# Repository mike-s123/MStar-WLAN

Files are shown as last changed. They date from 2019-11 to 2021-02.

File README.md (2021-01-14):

# MStar-WLAN

### What's new

Now supports collecting data in an [RRD](https://oss.oetiker.ch/rrdtool/), and charting that data using [JavascriptRRD](http://javascriptrrd.sourceforge.net). The interval for traditional logging can now be set. Updated hardware for USB Type-C.

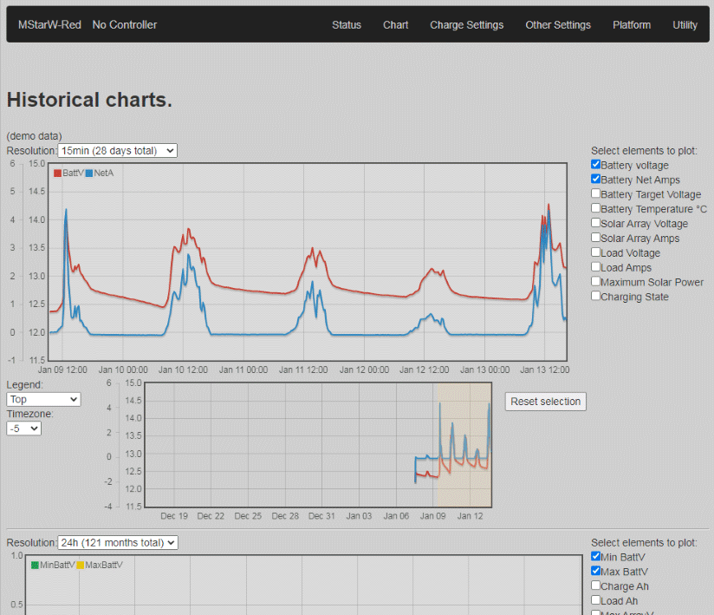
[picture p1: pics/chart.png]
image of chart


## Overview

This project includes both a software and hardware design for interfacing to a [Morningstar](https://www.morningstarcorp.com/) solar controller via wireless LAN (WiFi). It's 99.99% working, with features still being added. The development core is an ESP32-WROVER-B 16MB (~$5 from Mouser) or an ESP32 DevkitC v4. A complete build should be ~$40, ignoring your time. Those platforms were chosen because they're available with a relatively large flash (16 MiB) for storing files, which allows having documentation and support for multiple solar controllers on-board. Supports MS-View compatible logging of controller info to an SD card, in addition to a debugging log. There's support for monitoring and configuration via a web interface, Modbus/TCP, and a RESTful JSON API. The UI fits well on a cell phone screen.

A core with less flash memory should work fine as long as the "data" directory will fit. The code supports moving content from flash to the SD Card. If a file is not found in flash, it will look for it on the SD Card. Delete everything in the "data" directory, copy everything from "data-small" into "data", and then copy everything in the "Put on SD Card - small" directory onto an SD Card to use an ESP32 board with less flash. The additional flash memory on the recommended modules is there in order to support all the static files even without an SD Card present. An SD Card is required for logging and charting.

It is written using the [Arduino IDE](https://www.arduino.cc/en/Main/Software), which is a bit "odd", hence code being split for clarity amongst multiple .h files. If you know how to do it better, please contribute. Yes, I know some of the code is butt-ugly. But it works. Function over form.

The printed circuit board was done in [Eagle](https://www.autodesk.com/products/eagle/overview).

Development has been done testing against the Prostar MPPT and Prostar PWM Gen3 controllers, and the information/config files for those have been provided. Other controllers will need to have register definition .csv files (see data/csv_file_desc.txt) added. Might need to do some work for register datatypes - Morningstar has many (really, what were they thinking creating one based on a 16 bit int, n·316.67·2^-15, and multiple similar) and they've changed over time. It should also be able to support Sunsavers (SSDuo, SS-MPPT), and Tristar (TS-45, TS-60, TS-MPPT-x) controllers (i.e. ones supporting Modbus). Morningstar isn't consistent with naming or numbering the registers, so such support will require more than just creating the .csv files. PS.h supports ProStar MPPT and PWM models and can be used as a template on how to support other models. Changes to _local.js_ may also be needed.

MODBUS-TCP works with Morningstar's MSView, allowing it to be used to monitor and configure a controller wirelessly. To do that, in MSView, do "Devices/Manual connection", select your controller type, select Connection Type Remote, and enter the IP address or DNS name of the MStar-WLAN. OK. Then right click on the controller in the left column and "connect." MSView first downloads any logs, so may take a minute before much else happens. It should work with any controller supporting MODBUS, it doesn't depend on the specific support for a controller, so if nothing else, it can be a wireless alternative to their USB/RS-232 to MeterBus converters (other than for doing firmware updates).

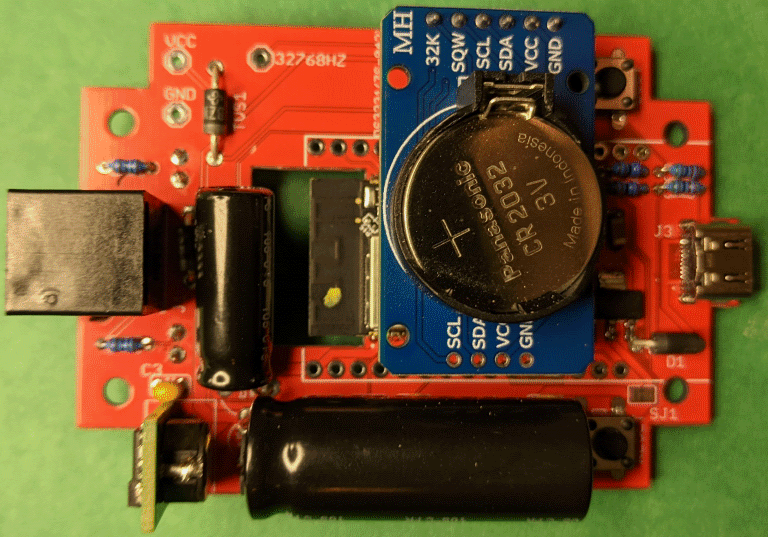
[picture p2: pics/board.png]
image of hardware


## Getting Started

The code will run on a bare ESP32 devboard, but obviously can't talk to a controller so the status and config pages won't do much. But you can check it out without much effort.

To do anything useful, hardware is needed to interface with a Morningstar controller. Morningstar uses a proprietary half-duplex (open collector, see /data/img/Schematic.png) Modbus interface. A circuit board layout is provided which includes all the necessary interfacing circuitry, even drawing power from the Morningstar controller. It supports an optional real time clock to support timestamped logging. It also supports ntp, so even without an RTC it can timestamp logs if it has a WLAN connection to the Internet.

Circuit board info is found in the "hardware/pcb" directory, where there are Eagle .brd, .sch and .lbr files, along with some parts info. The .zip file contains CAM files ready to send to [JLCPCB](https://jlcpcb.com/quote#/) to get boards made. Currently, 5 boards will cost you less than $10, if you will wait about a month to get them. The PCB was made to allow either "through hole" components (with an ESP32 DevkitC), or SMT ones (using a WROVER). If you use a DevkitC, note that 16 MiB ones aren't easy to find, so you'll probably still want to have the SD Card (which is needed for logging and charting).

I usually have a few circuit boards around. If you can contribute to the project, contact me and I might send you one. Even if you can't contribute, I might sell you one for a very reasonable price. If you don't solder, and want a pre-built one, contact me - this isn't meant to be a money maker (it's a hobby project), but I do value my time.

### Prerequisites

Development is currently being done with Arduino IDE 1.8.13, and tracking espressif / arduino-esp32ESP32 

Library requirements are noted in the .ino file. The [ESP32](https://github.com/espressif/arduino-esp32) core for Arduino needs to be installed. I follow the current development branch. View the README in the forArduinoIDE folder for info on setting up a custom board and partitions in the Arduino IDE (for Windoze, anyway).

Initially, the "data" directory needs to be uploaded to the board from the IDE (using the [arduino-esp32fs-plugin](https://github.com/me-no-dev/arduino-esp32fs-plugin)) or via OTA (Utility tab, will require files on the SD Card).

Uploadable code (MStar-WLAN.ino.esp32.bin) and flash (MStar-WLAN.littlefs.bin) binaries are provided here, which can be flashed using the OTA capability after the initial setup. 

The data/ctl/*.csv files are used to define the different controllers. data/csv_file_desc.txt describes the format.

## Operation

Using a standard "rollover" (tabs on the same side of the cable) 6P6C ("RJ12") cable, connect to the Meterbus port of a Morningstar controller. Don't worry - it's protected if wired wrong. A 4P4C cable should also work, if it's short (fewer wires for power).

The MStar-WLAN will initially come up as a wireless access point with SSID starting with "MStar" and a PSK of "morningstar". It will have an address of 192.168.4.1. 

The web interface has some minimal security. Any page which allows configuration changes is protected with default username "admin", password "setup". To do an Over-The-Air (OTA) firmware update or change security settings, the default username is "admin", password "update".

SSID, names and passwords can be changed (Utility tab, Security settings). To reset to defaults, press and hold the BOOT button for more than 5 seconds after powering up (WLAN LED will fast blink when you're held the button long enough).

Connecting to http://192.168.4.1/ will display the main status page. Other pages are shown along the top. "Utility/Wireless settings" will allow you to connect to a wireless network, from which the MStar-WLAN will get an address via DHCP (check your DHCP server to see what address it received). You can then connect to the internal web server at that address. The firmware also informs the DCHP server with a (statistically) unique hostname of the form "MStar-WLAN-xxxxxx", where the xs are the last 3 octets of the MAC address in hex.

OTA updates are done from the Utility tab, "Update WLAN module firmware" link. OTA updates of the flash (/data) image are also possible. File names are "MStar-WLAN.ino.esp32.bin" and "MStar-WLAN.littlefs.bin". 

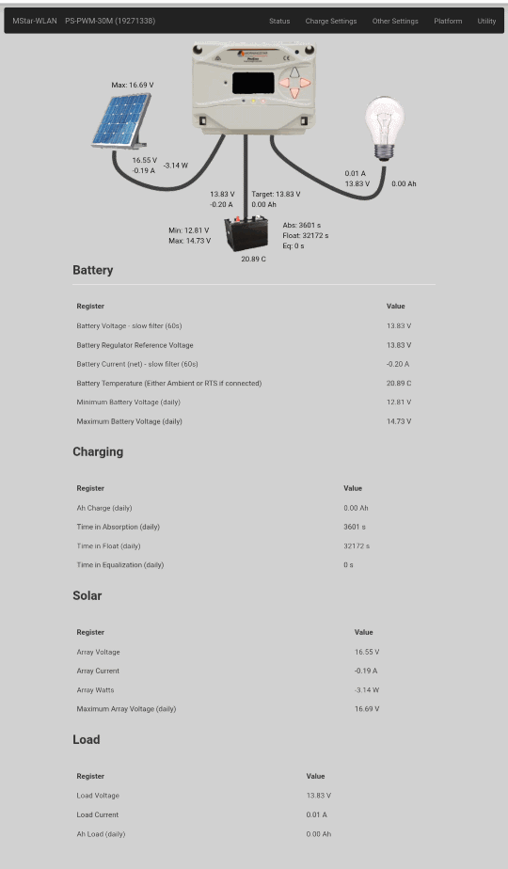
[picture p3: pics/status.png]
image of status page


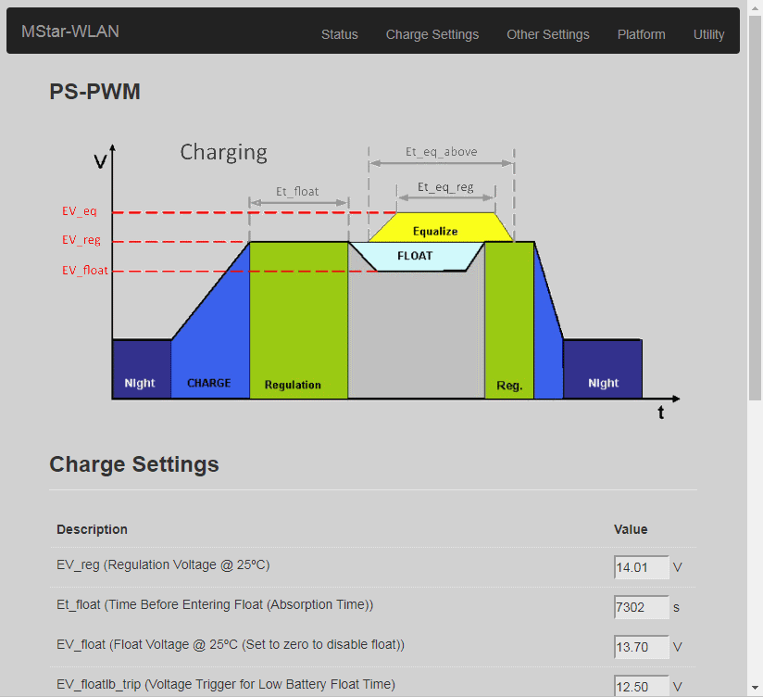
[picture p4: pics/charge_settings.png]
image of charge settings page


## Known issues

When powered by the controller, it will sometimes reset at 2AM. I think this is somehow related to the ezTime library, which is really the only thing that time is special to (it's the DST changeover time for my timezone). It doesn't seem to happen when powered by USB, and doesn't seem to happen with a PS-MPPT (only a PWM). Perhaps a short race condition which causes a greater than normal power draw. It's not a big issue - the solar controller isn't affected, and we'll simply reboot and resume operation in about a minute.

## Support

There is none, although you can certainly ask - if you're having a problem, you've probably found something which I'll eventually run into. You'll get a better response if you can well document a bug. This was a personal project, I'm freely offering it to others for non-commercial use. Feel free to contribute back if you can (don't do github pull requests, that would just be another thing for me to figure out how to make work, I'm not a regular git user.). Things which need attention or might be an important future direction are commented with "TODO".

## General answers to any question (pick one)

Yes.

No.

That's an important future direction.

That's a significant third-party opportunity.

## More Info

More info may be found under the data directory.

## Current work

The hardware supports one of the cheap Chinese DS3231 Real Time Clock boards. The software can be configured to connect to an NTP server, and if it does it will keep the RTC in sync (and trim its oscillator more accurately, too!). Either a good network connection is needed (for NTP), or an RTC, for accurate logging. 

## Important future directions

Possible additions: Include support for additional controllers (if someone has a broken one which might still talk MODBUS, feel free to donate). <s>Allow changing user/pass for config and update.</s> Static IP config. SMTP - email notifications for error or out-of-range conditions (or even daily updates). <s>Logging/graphing.</s> Support for simultaneous connection to multiple controllers. <s>Async web server.</s> Chunked responses. Provide "one click" charging settings for different batteries. Backup/restore settings. <s>Support connection to multiple, alternate SSIDs</s> (done). MQTT. SNMP. Serial passthrough, to allow a direct MS-View connection and firmware upgrades via USB. <s>Move large files to SD card.</s> ???.
 
## Author

* **Mike Sauve** - [mike-s123](https://github.com/mike-s123/)
Programming is not my day job, so don't be harsh about style or efficiency. Function over form. It's working for me, I hope it works for you. I formally learned on FORTRAN and PL/C. Later BASIC, assembly, and bash with a small bit of python. 98% as a hobby. OO stuff is foreign to me. 

## License and copyrights

First up - if you clone/fork this, please let me know. It's not a requirement, just a request - I'd like to know who else is interested - I haven't found much interest/development for similar projects.

* Original work copyright by Mike Sauve, License [CC BY-NC](https://creativecommons.org/licenses/by-nc/4.0/legalcode)

* See [LICENSE.MD](https://github.com/mike-s123/MStar-WLAN/blob/master/LICENSE.md) for more detail.

* Hardware datasheets (in the hardware directory) are copyrighted by the manufacturers. They were all pulled off public websites. I believe it is fair use to have them here, where they're doing what they were intended to do - support the associated devices. If any complain, I'll remove them.

* Morningstar documentation (in data directory) is copyrighted by Morningstar. All of it was pulled off their public website, it is here simply to make things easier. I believe it is fair use to have them here, same reason as above. If Morningstar complains, I'll remove them.

* All libraries are copyright their respective owners. I think I've provided proper credit to all, and suitable links to the licenses.

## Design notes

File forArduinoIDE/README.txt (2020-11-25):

Board and partition info.
-------------------------

This can be added directly into the espressif/esp32 hierachy, or via symlinks.

MStar-WLAN_boards.txt is the board definition file.
The .csv files contain partition info for 16, 8, and 4 MB flash models.

===========
Adding to espressif/esp32. Board will be at bottom of list.

MStar-WLAN_boards.txt gets appended to ~/Documents/Arduino/hardware/espressif/esp32/boards.txt. The board will appear at the very end in the Arduino IDE.

The .csv files get copied to ~/Documents/Arduino/hardware/espressif/esp32/tools/partitions

=============
Using symlinks (assumes Git Bash available). Board will be listed in it's own section.

#!/bin/bash

CURDIR=$PWD
cd ~/Documents/Arduino/hardware/
rm -r MStar-WLAN
cd espressif/esp32
git pull -v
cd ~/Documents/Arduino/hardware/espressif/esp32/tools
./get.exe
cd ~/Documents/Arduino/hardware/
mkdir MStar-WLAN
mkdir MStar-WLAN/esp32
cd MStar-WLAN/esp32
ln -s ../../espressif/esp32/* .
rm boards.txt
rm platform.txt
cp ../../../MStar-WLAN/forArduinoIDE/MStar-WLAN_boards.txt ./boards.txt
cp ../../../MStar-WLAN/forArduinoIDE/MStar-WLAN_platform.txt ./platform.txt
cp ../../../MStar-WLAN/forArduinoIDE/*.csv ./tools/partitions
cp ../../../MStar-WLAN/forArduinoIDE/esptool.exe ./tools/esptool/esptool.exe
cd $CURDIR

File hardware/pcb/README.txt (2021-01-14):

Notes:
The .zip file in this folder is ready to submit to https://jlcpcb.com/ where you can get 5 boards, shipped for about US$10.

Components can be ordered through Mouser using this convenient cart: https://www.mouser.com/ProjectManager/ProjectDetail.aspx?AccessID=f1275ffe09

The other files are schematic, board layout, library and CAM processor files for Eagle CAD.

MStar-WLAN parts notes

Notes: C1 should be large, C12 low ESR. The power provided by the controller isn't always steady. The VR needs to be a switcher, a linear consumes too much power. The voltage regulator below seems to work best of those I tried, it's quite efficient in this application. As shown on the schematic, many parts are only needed if using a WROVER.

Resistors and caps aren't critical, other than below. Note that the resistor footprints are for miniature (3.4mm) ones.

Most parts are standard, these are somewhat specific:
C1 - Panasonic EEU-FR1V222L (2200 uF/35 VDC)
C12 - should be low ESR (Panasonic 	EEU-FS0J202LB 2000 uF/6.3 VDC)
D2 - Vishay SB140-E3, due to its low Vf.
VR1 - OKI-78SR-3.3/1.5-W36-C, supports large capacitive loads
VR2 - STM LDL1117S33R SOT-223-4 (only with WROVER)
J1 - 6P6C connector - Kycon GLX-N-66
J2 - SD Card - Hirose DM3BT-DSF-PEJS Note the contacts are away from the board.
J3 - USB C - JAE DX07S016JA3 This is the most difficult to hand solder SMD on the board. (only with WROVER)
Case - Hammond RL6105, board mounts to cover
USB/Serial - FTDI FT231XS-R SSOP-20 (only with WROVER) - to be correct, use ftprog (https://www.ftdichip.com/Support/Utilities.htm#FT_PROG) to program the chip with the FT231X.xml template, which tells the host to provide 500 mA to power the board when connected to a USB 2.1 host.
Reset - Rohm IMH3AT110 SOT-457 (only with WROVER)
TVS - BZW04-33 33V unidirectional

RTC - Not included in the Mouser project BOM. DS3231(common ZS-042 module, search Amazon for DS3231) Note that the header is installed on the side opposite the battery, so the battery is accessible when the module is in place. The module also needs to be modified so it doesn't try to charge the battery (remove the LED while you're at it). https://www.onetransistor.eu/2019/07/zs042-ds3231-battery-charging-circuit.html

- potential future for on-board RRD logging - FRAM Cypress CY15B108QN-40SXI (expensive, but 10^15 cycles) Fujitsu ‎MB85AS8MTPF-G-KBERE1‎ (not FRAM, ReRAM, but 1000000 cycles) Unfortunately, sharing SPI with the SD Card currently has issues.

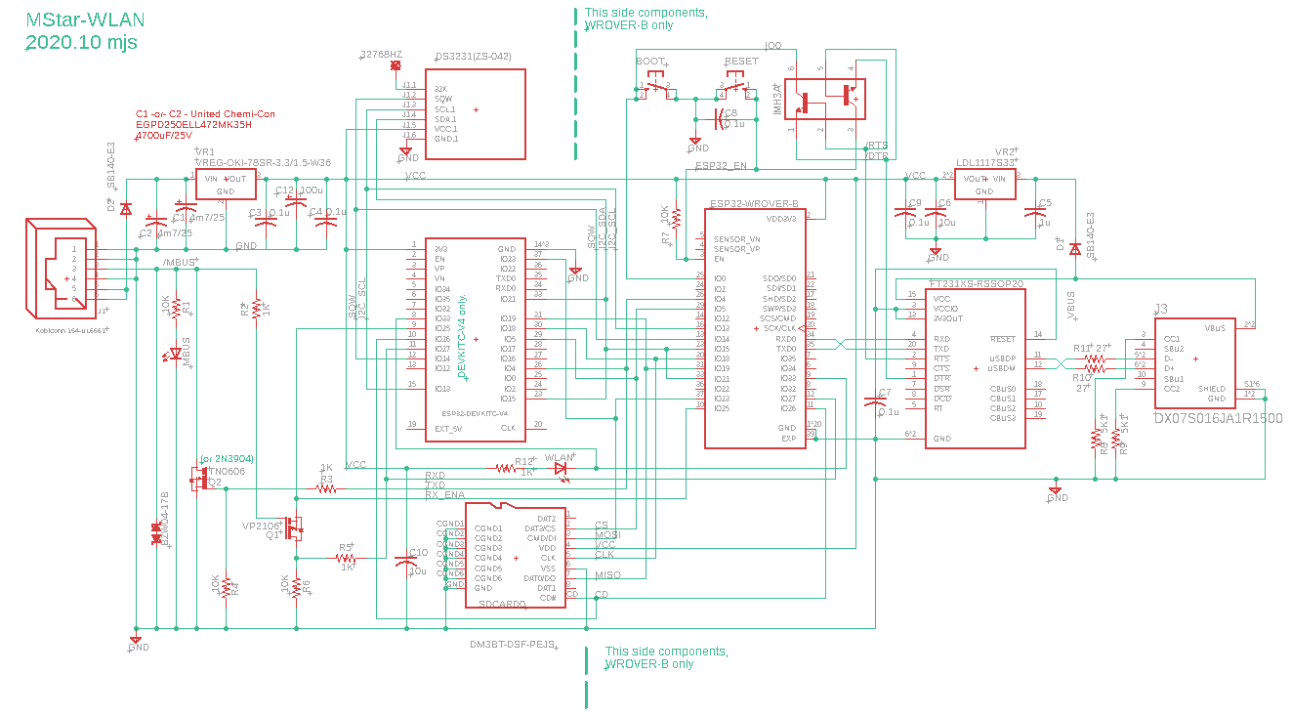
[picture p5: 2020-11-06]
Put on SD Card/img/Schematic.png

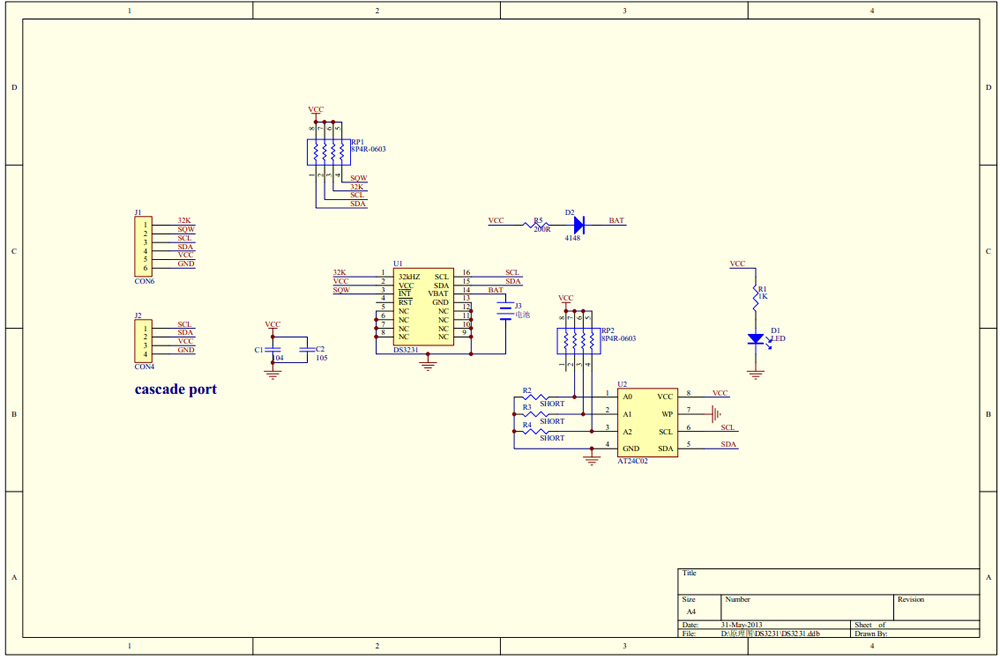
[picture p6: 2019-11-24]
hardware/DS3231schematic.jpg

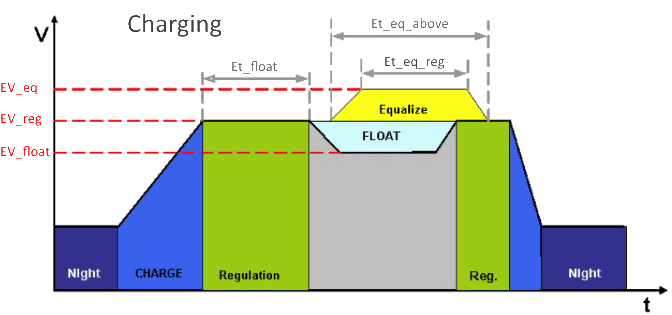
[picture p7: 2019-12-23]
Put on SD Card/img/charging.png

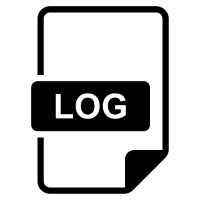
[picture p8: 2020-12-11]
Put on SD Card/img/logging.png

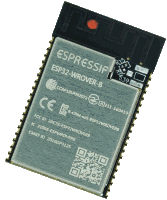
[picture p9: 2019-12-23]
Put on SD Card/img/wrover.png

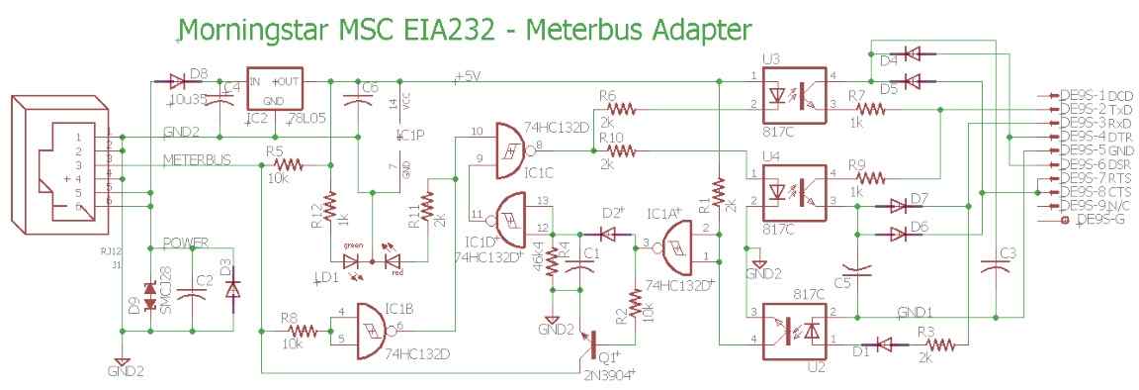
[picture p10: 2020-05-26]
Put on SD Card/img/MorningstarMSC.jpg

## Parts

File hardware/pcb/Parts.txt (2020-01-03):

MStar-WLAN parts list

Notes: C1 must be large, the power provided by the controller isn't always steady. The VR needs to be a switcher, a linear consumes too much power. The voltage regulator below seems to work best of those I tried, it's quite efficient in this application. As shown on the schematic, many parts are only needed if using a WROVER.

Resistors and caps aren't critical, other than below.

Most parts are standard, these are specific:
C1 - United Chemi-Con EGXF250ELL202MJ30S (2000uF/25V, 10mm dia, 30mm long)
D2 - Vishay SB140-E3, due to its low Vf.
VR - OKI-78SR-3.3/1.5-W36-C
VR - STM LDL1117S33R SOT-223-4 (only with ESP32)
6P6C connector - Kobiconn 154-UL6661
J3 - microUSB Hirose ZX62R-B-5P(30) (only with ESP32)
Case - Hammond RL6105
USB/Serial - FTDI FT231XS-R SSOP-20 (only with ESP32)
Reset - Rohm IMH3AT110 SOT-457 (only with ESP32)
RTC - DS3231(ZS-042 module) Note that the header is installed on the side opposite the battery, so the battery is accessible when the module is soldered in place.
MicroSD socket - Hirose DM3BT-DSF-PEJS
TVS - BZW04-26B

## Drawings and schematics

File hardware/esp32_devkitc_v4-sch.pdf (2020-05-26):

# ESP32 Module

# Power Supply

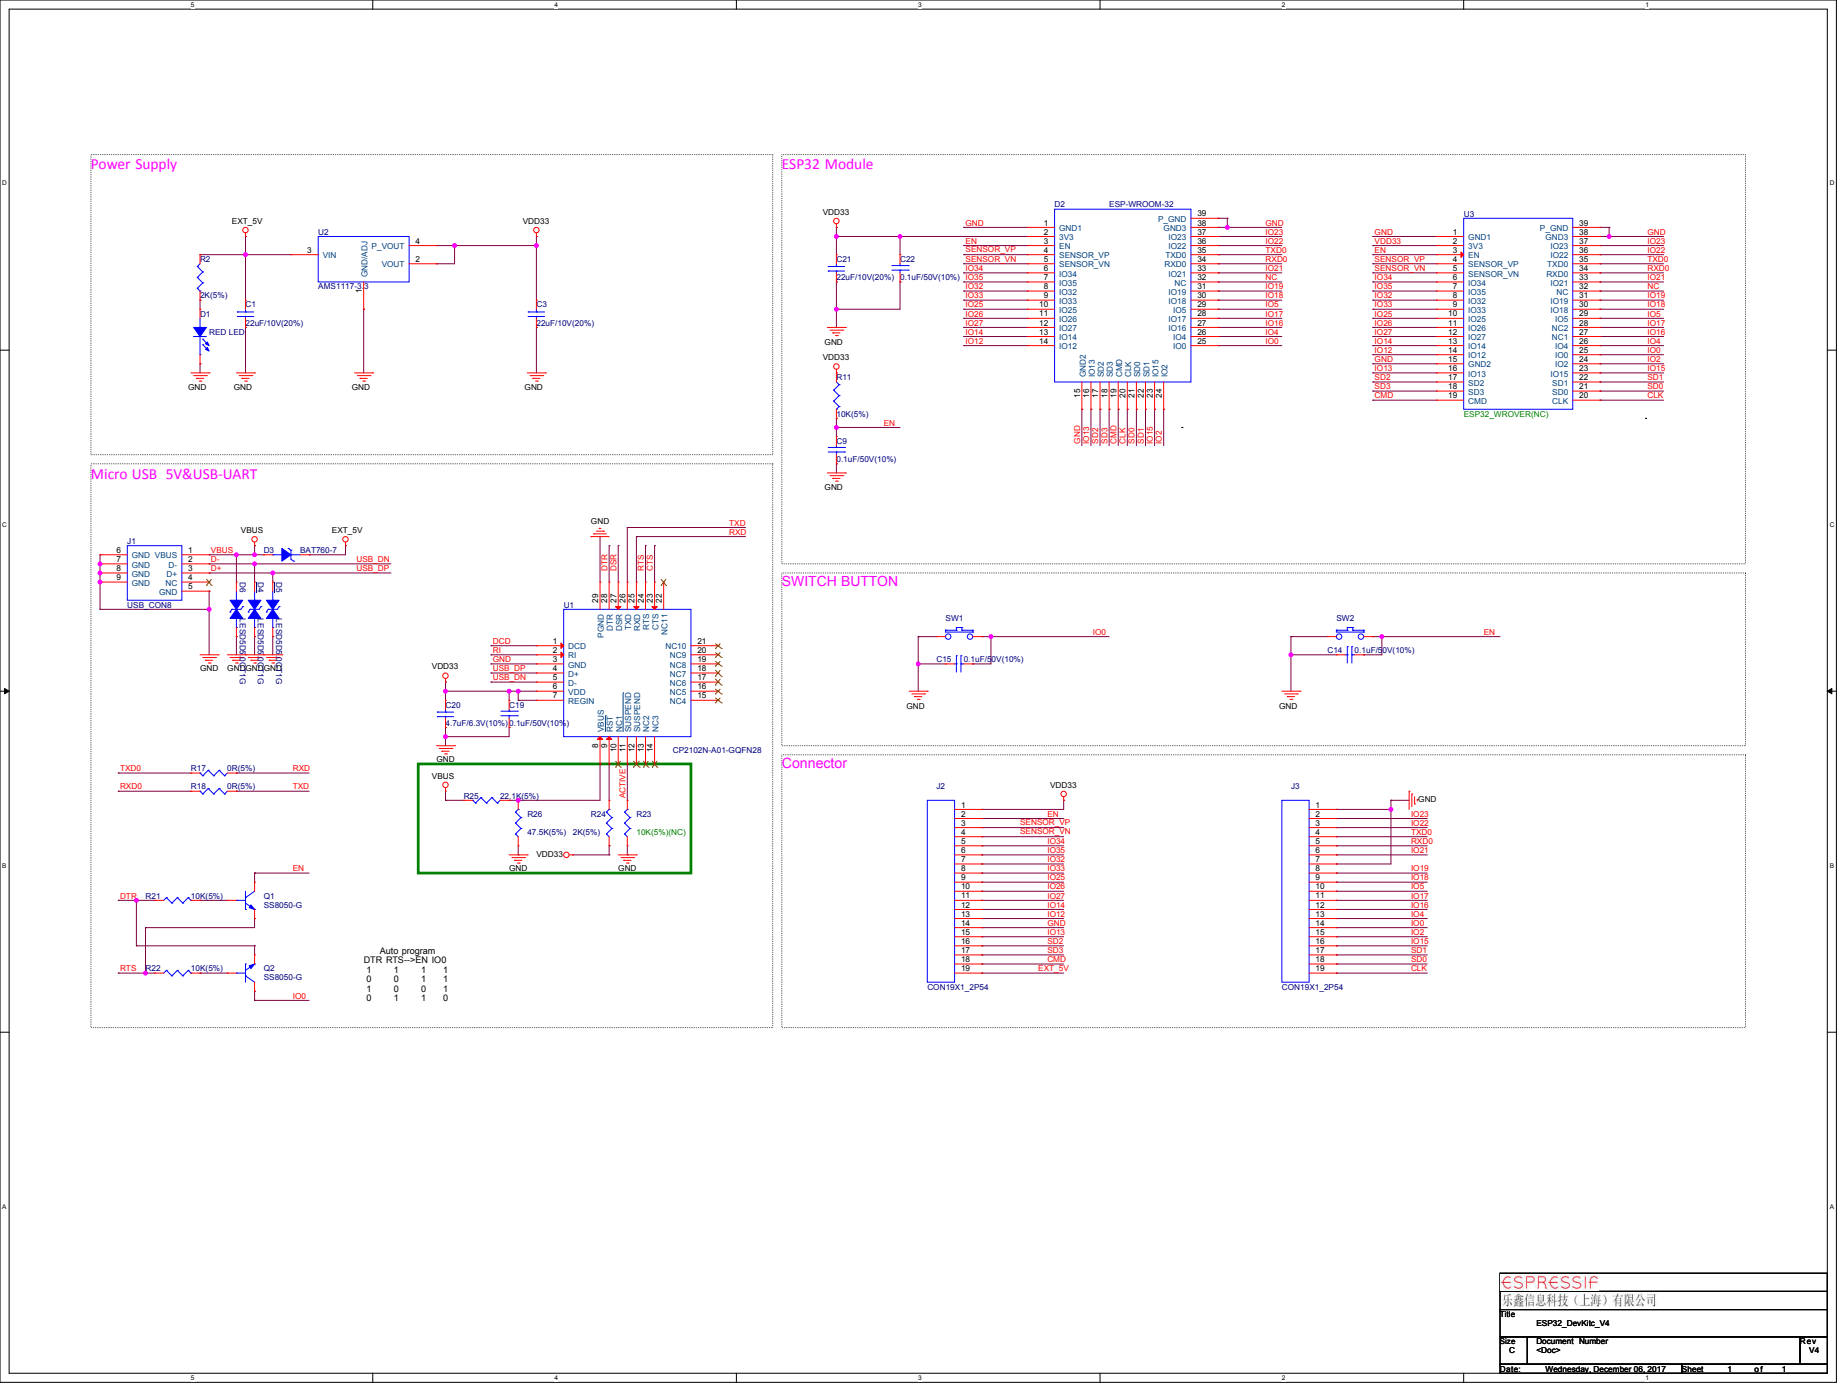
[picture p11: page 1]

Micro USB 5V&USB-UART

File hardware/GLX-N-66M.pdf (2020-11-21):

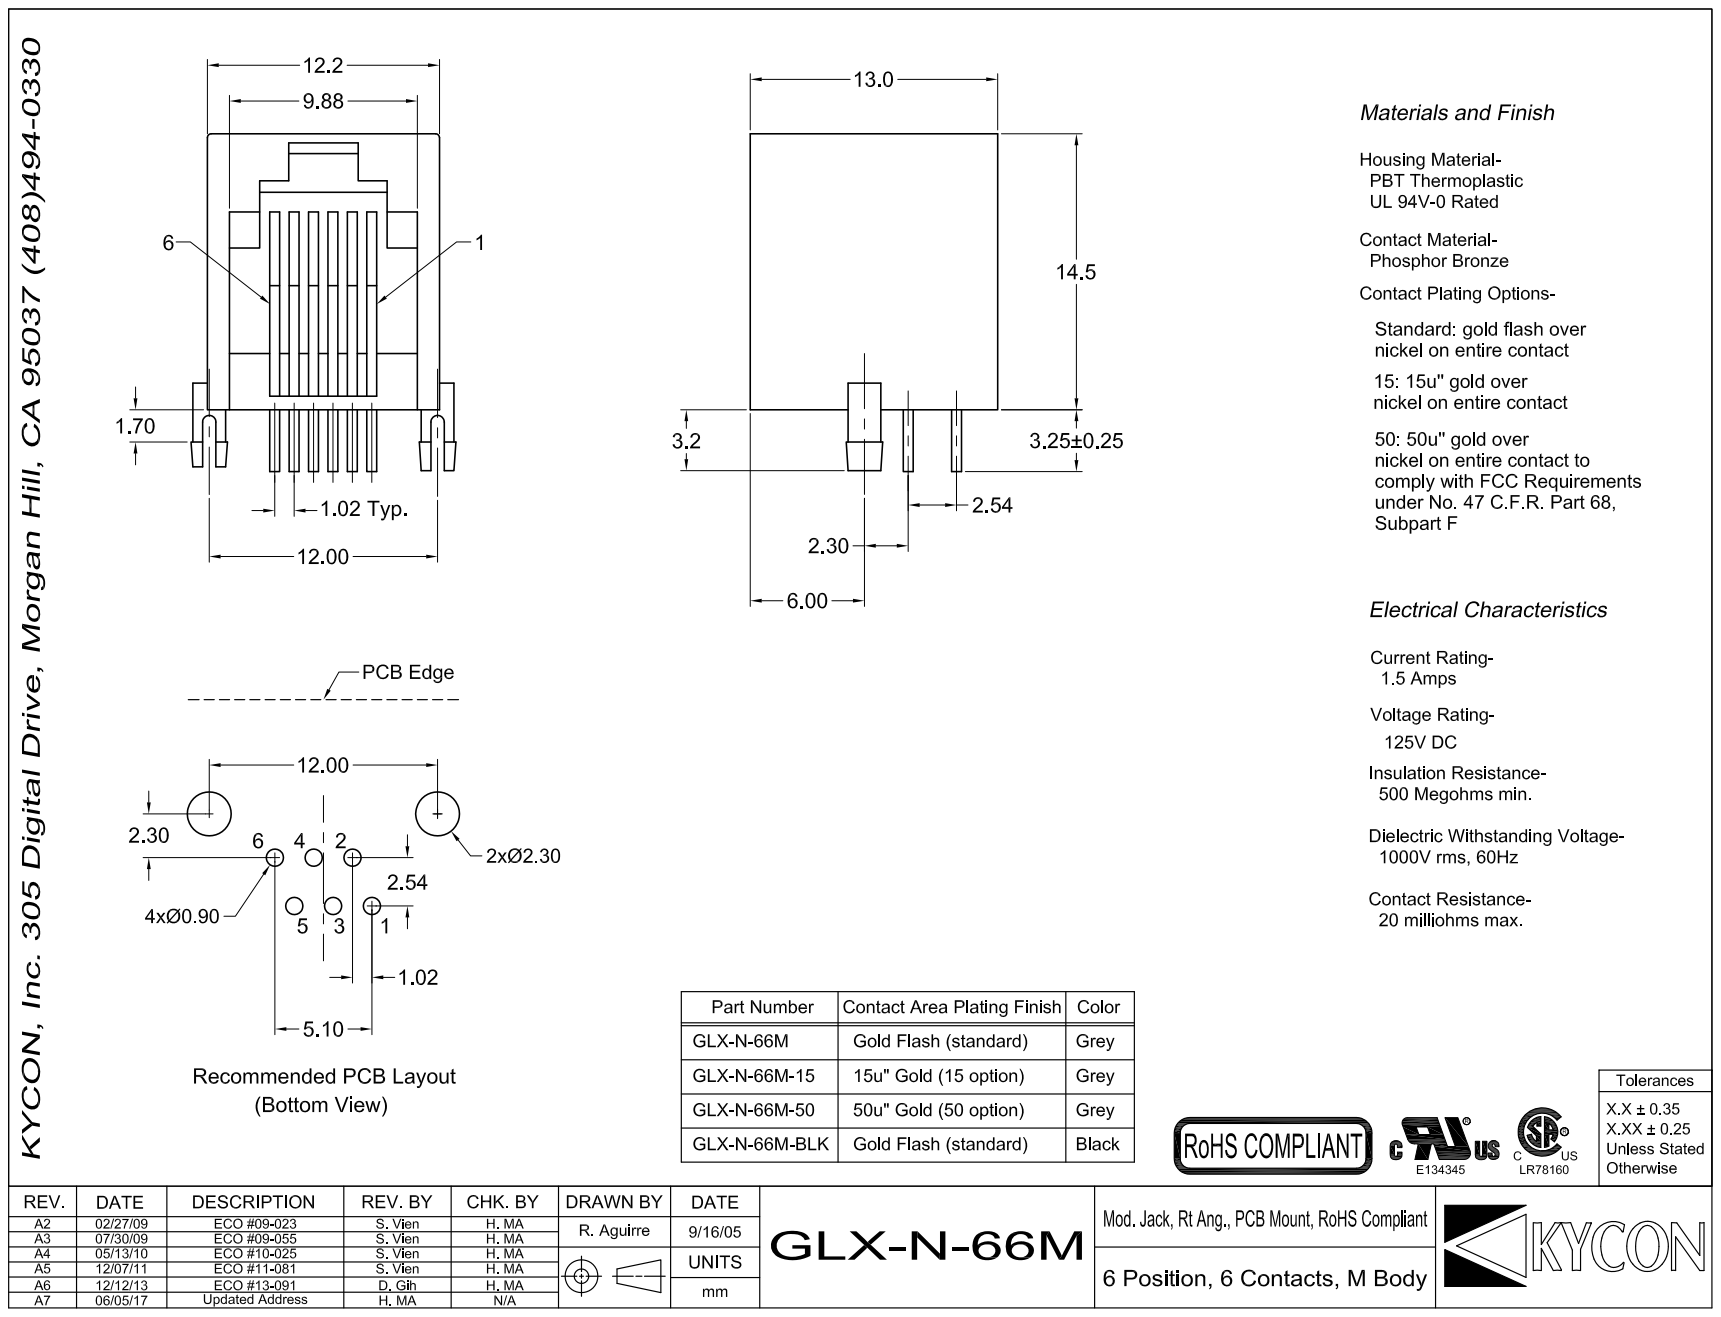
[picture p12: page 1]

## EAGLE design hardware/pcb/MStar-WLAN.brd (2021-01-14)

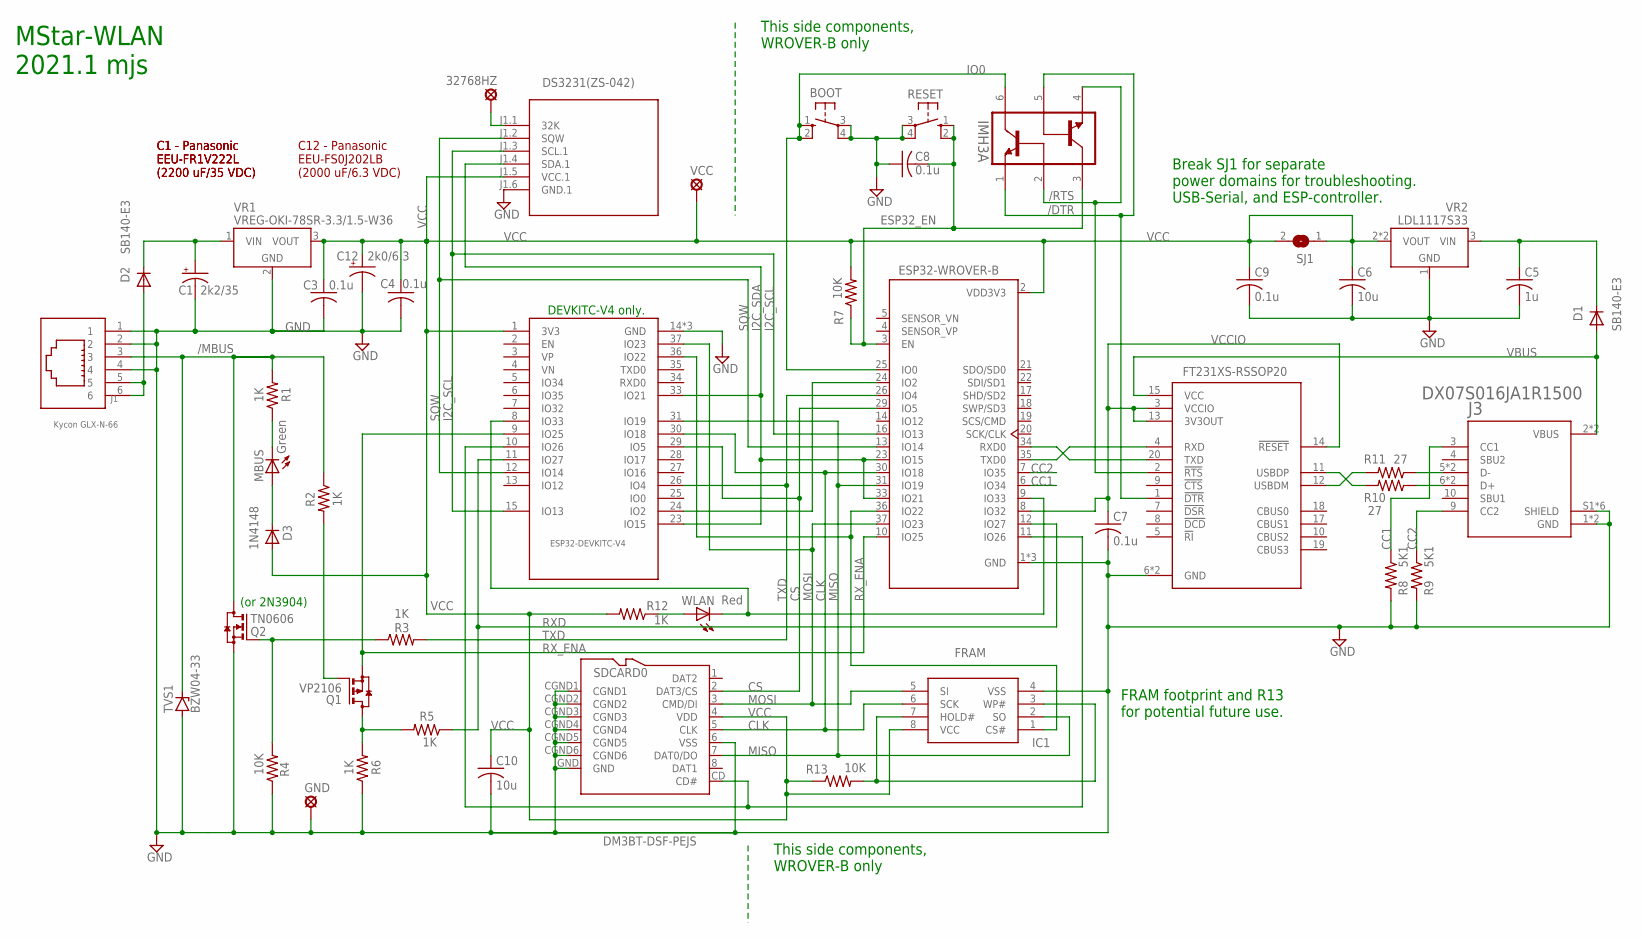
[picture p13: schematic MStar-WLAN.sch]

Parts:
32768HZ: MCS10B
BOOT: PTS645SM432LFS; B3F-10XX
C1: 2k2/35; E5-4
C3, C4, C7, C8, C9: 0.1u; C025-024X044
C5: 1u; C1206
C6, C10: 10u; C1206
C12: 2k0/6.3; E5-6
D1, D2: SB140-E3; DO41-7.6
D3: 1N4148; DO35-7
DS3231(ZS-042): RTC-DS3231-AT24C32-6
ESP32-WROVER-B: ESP32-WROVER-I; XCVR_ESP32-WROVER-I
FT231XS: FT231XS-RSSOP20; SSOP20
GND: MCS10B
IC1: FRAM; SO-08M
IMH3A: IMH3ATSOP6; TSOP6
J1: Kycon GLX-N-66; 6P6C
J3: DX07S016JA1R1500; JAE_DX07S016JA1R1500
MBUS: Green; LED3MM
Q1: VP2106; TO92
Q2: TN0606; TO92
R1, R2, R3, R5, R6, R12: 1K; 0204/5
R4, R7: 10K; 0204/5
R8, R9: 5K1; 0204/5
R10, R11: 27; 0204/5
R13: 10K; R1206
RESET: PTS645SM432LFS; B3F-10XX
SDCARD0: DM3BT-DSF-PEJS
SJ1: SJ
TVS1: BZW04-33; DO41Z10
U$1: ESP32-DEVKITC-V4-NOSD
VCC: MCS10B
VR1: VREG-OKI-78SR-3.3/1.5-W36; OKI-78SR
VR2: LDL1117S33; SOT223
WLAN: Red; LED3MM

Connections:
/DTR: FT231XS.1 (!DTR), IMH3A.1 (Q1E), IMH3A.5 (Q2B)
/MBUS: J1.3, Q2.D, R1.2, R2.1, TVS1.C
/RTS: FT231XS.2 (!RTS), IMH3A.2 (Q1B), IMH3A.4 (Q2E)
CC1: ESP32-WROVER-B.6 (IO34), J3.3 (CC1), R8.1
CC2: ESP32-WROVER-B.7 (IO35), J3.9 (CC2), R9.1
CD: ESP32-WROVER-B.11 (IO26), SDCARD0.CD (CD#), U$1.10 (IO26)
CLK: ESP32-WROVER-B.30 (IO18), IC1.6 (SCK), SDCARD0.5 (CLK), U$1.30 (IO18)
CS: ESP32-WROVER-B.29 (IO5), SDCARD0.2 (DAT3/CS), U$1.29 (IO5)
ESP32_EN: C8.2, ESP32-WROVER-B.3 (EN), IMH3A.3 (Q2C), R7.1, RESET.1 (S), RESET.2 (S1)
GND: BOOT.3, BOOT.4 (P1), C1.-, C3.2, C4.2, C5.2, C6.2, C7.2, C8.1, C9.2, C10.2, C12.-, DS3231(ZS-042).J1.6 (GND.1), ESP32-WROVER-B.1 (GND), ESP32-WROVER-B.15 (GND), ESP32-WROVER-B.38 (GND), FT231XS.6 (GND), FT231XS.16 (GND), GND.MP, IC1.4 (VSS), J1.1, J1.2, J1.4, J3.1 (GND), J3.12 (GND), J3.S1 (SHIELD), J3.S2 (SHIELD), J3.S3 (SHIELD), J3.S4 (SHIELD), J3.S5 (SHIELD), J3.S6 (SHIELD), Q2.S, R4.1, R6.1, R8.2, R9.2, RESET.3, RESET.4 (P1), SDCARD0.6 (VSS), SDCARD0.CGND1, SDCARD0.CGND2, SDCARD0.CGND3, SDCARD0.CGND4, SDCARD0.CGND5, SDCARD0.CGND6, SDCARD0.GND, TVS1.A, U$1.14 (GND), U$1.32 (GND), U$1.38 (GND), VR1.2 (GND), VR2.1 (GND)
I2C_SCL: DS3231(ZS-042).J1.3 (SCL.1), ESP32-WROVER-B.16 (IO13), U$1.15 (IO13)
I2C_SDA: DS3231(ZS-042).J1.4 (SDA.1), ESP32-WROVER-B.23 (IO15), ESP32-WROVER-B.33 (IO21), U$1.23 (IO15), U$1.33 (IO21)
IO0: BOOT.1 (S), BOOT.2 (S1), ESP32-WROVER-B.25 (IO0), IMH3A.6 (Q1C)
MISO: ESP32-WROVER-B.31 (IO19), IC1.2 (SO), SDCARD0.7 (DAT0/DO), U$1.31 (IO19)
MOSI: ESP32-WROVER-B.37 (IO23), IC1.5 (SI), SDCARD0.3 (CMD/DI), U$1.37 (IO23)
unnamed: MBUS.K (C), R1.1
unnamed: Q2.G, R3.1, R4.2
unnamed: Q1.G, R2.2
unnamed: 32768HZ.MP, DS3231(ZS-042).J1.1 (32K)
unnamed: ESP32-WROVER-B.36 (IO22), IC1.1 (CS#), U$1.36 (IO22)
unnamed: IC1.3 (WP#), IC1.7 (HOLD#), R13.2
unnamed: D3.C, MBUS.A
unnamed: ESP32-WROVER-B.24 (IO2), U$1.24 (IO2)
unnamed: Q1.D, R5.2, R6.2
unnamed: D2.A, J1.5, J1.6
unnamed: C5.1, D1.C, VR2.3 (VIN)
unnamed: R12.1, WLAN.A
RAW12: C1.+, D2.C, VR1.1 (VIN)
RXD: ESP32-WROVER-B.12 (IO27), R5.1, U$1.11 (IO27)
RXD0: ESP32-WROVER-B.34 (RXD0), FT231XS.20 (TXD)
RX_ENA: ESP32-WROVER-B.10 (IO25), Q1.S, U$1.9 (IO25)
SQW: DS3231(ZS-042).J1.2 (SQW), ESP32-WROVER-B.13 (IO14), U$1.12 (IO14)
TXD: ESP32-WROVER-B.26 (IO4), R3.2, U$1.26 (IO4)
TXD0: ESP32-WROVER-B.35 (TXD0), FT231XS.4 (RXD)
USBD+: J3.6 (D+), J3.7 (D+), R10.1
USBD-: J3.5 (D-), J3.8 (D-), R11.1
USBDM: FT231XS.12 (USBDM), R11.2
USBDP: FT231XS.11 (USBDP), R10.2
VBUS: D1.A, FT231XS.15 (VCC), J3.2 (VBUS), J3.11 (VBUS)
VCC: C3.1, C4.1, C6.1, C9.1, C10.1, C12.+, D3.A, DS3231(ZS-042).J1.5 (VCC.1), ESP32-WROVER-B.2 (VDD3V3), IC1.8 (VCC), R7.2, R12.2, R13.1, SDCARD0.4 (VDD), SJ1.1, SJ1.2, U$1.1 (3V3), VCC.MP, VR1.3 (VOUT), VR2.2 (VOUT), VR2.4 (VOUT)
VCCIO: C7.1, ESP32-WROVER-B.8 (IO32), FT231XS.3 (VCCIO), FT231XS.13 (3V3OUT), FT231XS.14 (!RESET)
WLAN_LED: ESP32-WROVER-B.9 (IO33), U$1.8 (IO33), WLAN.K (C)

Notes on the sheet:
MStar-WLAN 2021.1 mjs
C1 - Panasonic EEU-FR1V222L (2200 uF/35 VDC)
This side components, WROVER-B only
DEVKITC-V4 only.
(or 2N3904)
C12 - Panasonic EEU-FS0J202LB (2000 uF/6.3 VDC)
Break SJ1 for separate power domains for troubleshooting. USB-Serial, and ESP-controller.
FRAM footprint and R13 for potential future use.

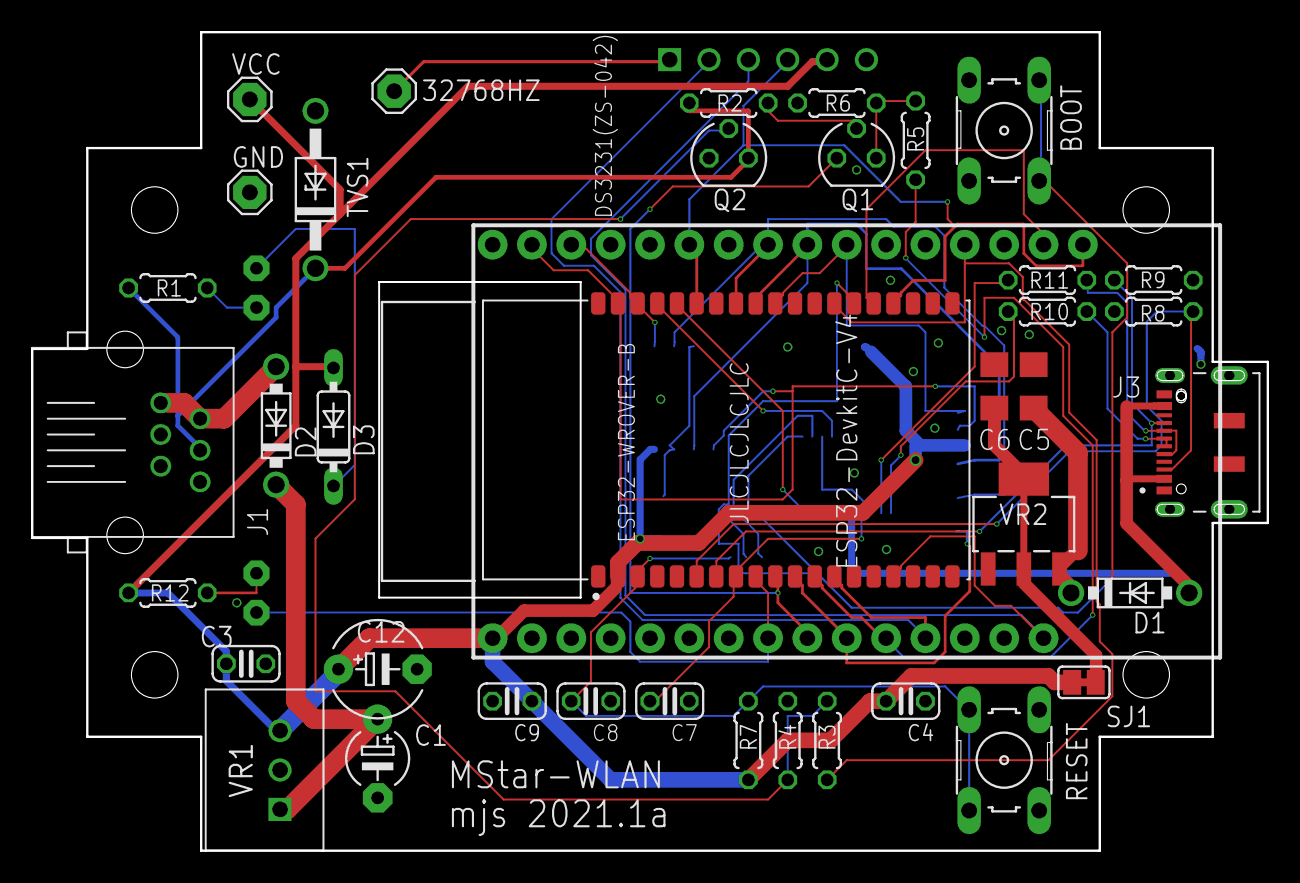
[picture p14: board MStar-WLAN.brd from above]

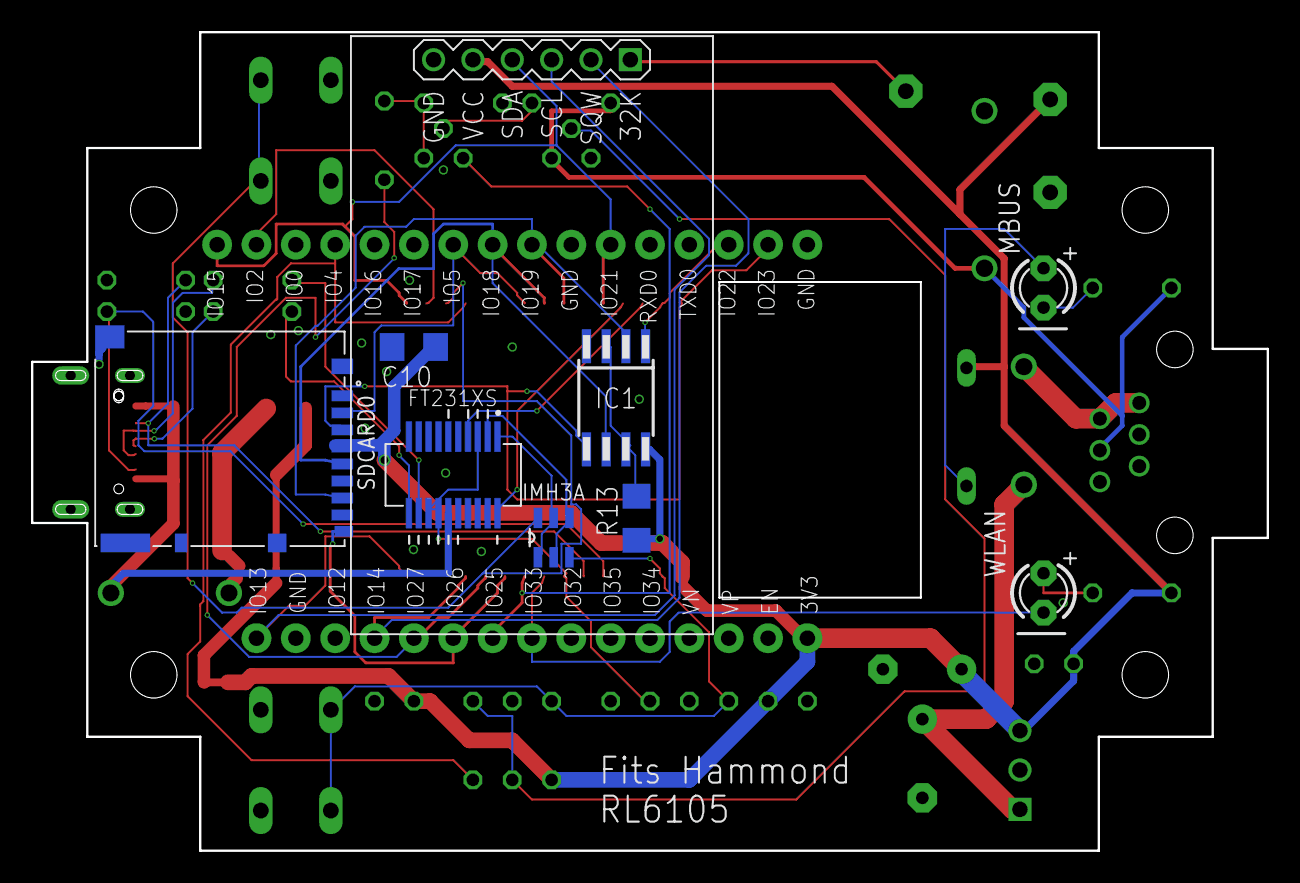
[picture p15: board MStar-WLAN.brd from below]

Board: 2 copper layers, 79.8 x 52.8 mm, 48 parts (9 on the bottom side), 42 nets.

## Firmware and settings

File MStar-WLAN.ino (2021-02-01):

 /*
 * MStar-WLAN 2020 mjs
 *   
 *  ESP32 - WROVER-B preferred for PSRAM. 16 MB flash is also preferred, But others are accmodated. 
 *  Included are custom partitions (e,g, WROVER 16 MB w/13 MB FS with modified files)
 *  
 *  Arduino IDE choices:
 *   lwIP: v2 higher bandwidth
 *   vTables: IRAM
 *   240 MHz
 *   
 *  ESP32 - WROOM (4 MB), use "data-small" folder for littlefs, put other files on SD-Card.
 *    -ESP32 Dev Module
 *    -Default 4 MB w/littlefs (1.2 MB APP/1.5MB littlefs)
 *  
 *   Original work, License CC BY-NC, https://creativecommons.org/licenses/by-nc/4.0/legalcode
 *   All rights reserved. Some parts subject to other licenses as noted.
 *   
 *   Libraries from Arduino IDE, unless otherwise noted.
 *   
 *   Using Arduino IDE 1.8.13, ESP32 Arduino 1.0.5rc1
 */

using namespace std; 
#define SOFTWARE_VERSION "v2.210131"
#define SERIAL_NUMBER "000001"
#define BUILD_NOTES "ESP8266 support gone. Keep RTC in UTC. Dynamic updates of /status page.<br>\
                     Some changes for small flash. Change to ArduinoJSON 6, using PS_RAM.<br/>\
                     Allow WLAN and security settings. Allow reset to defaults. Change hostname.<br/>\
                     REST fixes. Get files from SD Card if not found on flash. Pulsing LED.<br/>\
                     Change to littlefs. Improve OTA. Serve important stuff from PROGMEM.<br/>\
                     Settable debug level. REST timeout. Modbus reliability. EEPROM>Preferences. <br/>\
                     Set controller logging period. Fahrenheit display. RRD/charting. Prep for email.<br/>\
                     Fix solar power calc. Fix min/max battV. Track current/max solar power correctly."

#define DEBUG_ON 1               // enable debugging output. If defined, debug_level can be changed during runtime.
                                 // 0 off, 1 least detail, 8 most detail, 9 includes passwords

#ifdef DEBUG_ON
  #define BAUD_LOGGER 115200        // baud rate for logging
  //#define DEBUG_ESP_HTTP_SERVER
  //#define DEBUG_ESP_CORE
  //#define EZT_DEBUG DEBUG           // for EZTime
#endif
#define STRINGIFY(x) #x
#define TOSTRING(x) STRINGIFY(x) // see https://stackoverflow.com/questions/240353/convert-a-preprocessor-token-to-a-string
/*
 * If we define WIFI_MODE_AP_STA, it will both be an AP and try to connect as a station.
 * If not defined, we're a station if able to connect to a configured WLAN, otherwise
 * we turn into an AP. When an AP, if there are WLANs configured, it will try to connect
 * every few minutes if there is no client connected.
 */
#define WIFI_MODE_AP_STA                // define to run AP while also connected as station
#define PS_RAM    // use WROVER PS-RAM
#include <string>
#include <sstream>
#include <Preferences.h>
#include <FS.h>       // 1.0
#include <Wire.h>     // 1.0.1

#include "ESPAsyncWebServer.h"  // 1.2.0 
#include <WiFi.h>               // 1.0
#include <WiFiMulti.h>          //
#include <AsyncTCP.h>           // 1.0.3
#include <WebAuthentication.h> 
#include <ESPmDNS.h>
//#include <ESP32Ping.h>          // https://github.com/marian-craciunescu/ESP32Ping
#include <Update.h>
#include <FFat.h>                 // Needed for rrdtool
#include "esp_err.h"
#include "esp_log.h"
#include "esp_vfs_fat.h"
#define USE_LITTLEFS
#ifdef USE_LITTLEFS
  #define FILESYSTEM LITTLEFS
  #define FS_NAME "littlefs"
  #include <LITTLEFS.h>         // GPL v2, https://spdx.org/licenses/BSD-3-Clause.html, LGPL https://github.com/marian-craciunescu/ESP32Ping/blob/master/LICENSE
#else
  #define FILESYSTEM SPIFFS
  #define FS_NAME "SPIFFS"
  #include <SPIFFS.h>
#endif
#include <SFFS.h>         // from Arduino IDE, BSD 3-Clause License https://github.com/pholmes2012/Simple_FRAM_FileSystem/blob/master/LICENSE 

#include <SD.h>                 // 1.0.5
#include <rrd.h>                // 1.0.1 - https://github.com/lbernstone/rrdtool_ESP32/ GPLv2
#include <SPI.h>
#include <sys/time.h>
//  #include "SdFat.h"
#include <HardwareSerial.h>
#include "driver/uart.h"
//#include "StreamUtils.h"              // 1.5.0 https://github.com/bblanchon/ArduinoStreamUtils (MIT License)
#include <ESP_Mail_Client.h>            // 1.0.13 https://github.com/mobizt/ESP-Mail-Client (MIT License)
#include <ArduinoJson.h>                // Benoit Blanchon 6.17.2, via IDE
#include <WiFiClient.h>
//#include <WiFiClientSecure.h>
//#include <WiFiClientSecureAxTLS.h>
//#include <WiFiClientSecureBearSSL.h>

#include <WiFiServer.h>
//#include <WiFiServerSecure.h>
//#include <WiFiServerSecureAxTLS.h>
//#include <WiFiServerSecureBearSSL.h>
#include <WiFiUdp.h>
#include <ModbusMaster.h> // 2.0.1 Doc Walker, via IDE
#include "driver/ledc.h"
#include "driver/gpio.h"
#include "soc/ledc_reg.h"
#include "soc/rtc_wdt.h"



#define PROGMEM_FILES               // serves important files from PROGMEM instead of flash,
                                    // reduces dependence on filesystem. OTA.js, local.js, local.css
                                    // if files are found on SD Card, they will be used instead
File logFile;                         // platform log file
String logFileName;
File ctl_logFile;                     // controller log file
#define CTL_LOGFILE "/ctl00000000.csv"        // default, must start with /
String ctlLogFileName = CTL_LOGFILE;
#ifdef EZT_DEBUG
  File ezt_logFile;                   // ez-time log file
  #define EZT_LOGFILE "/eztime.log"   // must start with /
#endif


//---------------------------
// definitions
//---------------------------

#define PREF_REALM "MStar-WLAN"  // realm (namespace) for preferences
#define WROVER  // if using WROVER-B, not devkit
#define CELSIUS true   // display Celsius or Fahrenheit
// change with http://xxx/cmd?celsius=false  (or true)

//security
#define WEB_USERNAME "admin"
#define WEB_PASSWORD "setup"
#define ROOT_USERNAME "admin"
#define ROOT_PASSWORD "update"
#define UPDATE_PATH "/update"
#define JSON_PASSWORD "imsure"
//#define nosec
#ifdef nosec
  #define WEB_USERNAME ""
  #define WEB_PASSWORD ""
  #define ROOT_USERNAME ""
  #define ROOT_PASSWORD ""
#endif

//wlan
#define AP_SSID "MStar"
#define AP_SSID_UNIQ                    // define to generate a unique SSID e.g. MStar-123456
// password, if used, must be 8-32 chars
#define AP_PSK  "morningstar"


#define HOSTNAME "MStarW"  // needs to be short - esp32 only does 12 char hostnames!

#define JSON_VERSION "1.0"                // changes with api changes
#define JSON_VERSION_MIN "1.0"            // changes when backward compatibility is broken
#define LEDC_timerbits          LEDC_TIMER_13_BIT

// GPIO 2 or 33 for WROVER-B board
#define WLAN_PIN_OLD  GPIO_NUM_2  // up through board 2020.2
#define WLAN_PIN      GPIO_NUM_33 // from 2020.10
#define RX_ENABLE_PIN GPIO_NUM_25 // RxEna to IO25, pin 10
#define RX_PIN        GPIO_NUM_27 // RxD to IO27, pin 12
#define TX_PIN        GPIO_NUM_4  // Txd to IO4, pin 26
#define SDA_PIN       GPIO_NUM_15 // GPIO 15  I2C SDA
#define SCL_PIN       GPIO_NUM_13 // GPIO 13  I2C SCL
#define SPI_SCLK      GPIO_NUM_18 // these are default pins for VSPI (SPI3)
#define SPI_MISO      GPIO_NUM_19 // just here for documentation
#define SPI_MOSI      GPIO_NUM_23
#define SD_CARD_CS    GPIO_NUM_5  // CS for SDCard
#define FRAM_CS       GPIO_NUM_22
#define SD_DETECT     GPIO_NUM_26 // SD card inserted, only for SDCard0
#define BOOT_SW       GPIO_NUM_0  // GPIO0 connected to BOOT switch
#define I2C_SDA_RESET GPIO_NUM_21 // https://www.forward.com.au/pfod/ArduinoProgramming/I2C_ClearBus/index.html
#ifdef WROVER
  #define USB_CC1_PIN GPIO_NUM_34  // USB Type-C CC1
  #define USB_CC2_PIN GPIO_NUM_35
  #define USB_PWR_DET GPIO_NUM_32  // to VCCIO
#endif
#define SD_CARD_LOG true           //log to SD card
#define CTLRRDFILENAME  /ctl00000000.rrd    // must start with /
#define CTLDRRDFILENAME /ctl00000000d.rrd    // must start with /
bool sd_card_log = SD_CARD_LOG;
bool sd_card_available = false;
volatile bool sd_card_changed = false;
bool needLogTime = true;  // whether we need to print time to the log

// MBus slave id of controller
#define mbusSlave 1

// controller type
#define MODEL "PS-PWM"

// modbus items
#define REG_ROWS 126
#define COIL_ROWS 20

// ----------------------------------------------------------------------------------------------------
// ------------------------------------------  Globals (mostly)  --------------------------------------
// ----------------------------------------------------------------------------------------------------

#ifdef DEBUG_ON
  int debug_level = DEBUG_ON;
#else
  int debug_level = 0;
#endif
/*
string web_username = WEB_USERNAME;
string web_password = WEB_PASSWORD;
string json_password = JSON_PASSWORD;
string json_version = JSON_VERSION;
string json_version_min = JSON_VERSION_MIN;
string ap_ssid = AP_SSID;
string ap_password = AP_PSK;
string ap_SSID = AP_SSID;
string root_username = ROOT_USERNAME;
string root_password = ROOT_PASSWORD;
string serialNumber = SERIAL_NUMBER;
*/
String web_username = WEB_USERNAME;
String web_password = WEB_PASSWORD;
String json_password = JSON_PASSWORD;
String json_version = JSON_VERSION;
String json_version_min = JSON_VERSION_MIN;
String ap_ssid = AP_SSID;
String ap_password = AP_PSK;
String ap_SSID = AP_SSID;
String root_username = ROOT_USERNAME;
String root_password = ROOT_PASSWORD;
String serialNumber = SERIAL_NUMBER;

const char *update_path = UPDATE_PATH;

String esid[4];
String epass[4];
int wlan_count=0;             // holds how many WLANs configured in EEPROM
boolean wlanRead = false;     // if we've read SSID/PSKs from EEPROM
boolean wlanSet = false;      // if we've added them to wifiMulti
boolean wlansAdded = false;   // if we've added WLANs to wifiMulti
boolean largeFlash = false;
enum ledStatusStates {lss_APCLIENT, lss_STATION, lss_IDLE, lss_NONE};
ledStatusStates blinkyState = lss_NONE;
boolean led_change_done = true;
boolean noController = true;
boolean psRAMavail = false;
boolean FRAMavail = false;
boolean daytime = true;
boolean celsius = CELSIUS;  // temperature in Celsius?
boolean vfs_fat_registered = false;
uint8_t myWDT=120;
time_t bootTime, nightTime;
unsigned long lastWLANtry;      // when we last tried to connected (or tried) to an AP
int mbAddr = mbusSlave;
String model = MODEL;
String fullModel = MODEL;
String ctlSerialNum = "00000000";
string sd_vfs_path = "/sdvfs";
string ctlRrdFileName = TOSTRING(CTLRRDFILENAME);
string ctlRrdFileFullPath = sd_vfs_path + ctlRrdFileName;
string ctlDRrdFileName = TOSTRING(CTLDRRDFILENAME);
string ctlDRrdFileFullPath = sd_vfs_path + ctlDRrdFileName;

unsigned long mbustries, mbuserrs, mbuserrs_recovered, lastFound = millis();
float vary;
byte mac[6];
String my_MAC;
String my_name;                 // for log file name
String my_hostname;             // for networking
String logLast="";
#define LOG_FREQ  15            // minutes between log entries
unsigned int log_freq = LOG_FREQ; 
static char log_print_buff[512];
FATFS* FATfs = NULL;
File fsUploadFile;              // a File object to temporarily store the received file

String referrer; 
ModbusMaster node;
WiFiServer modbusTCP(502);
WiFiClient modbusClient;
AsyncWebServer server(80);
AsyncCallbackWebHandler rrdHandler;
AsyncCallbackWebHandler drrdHandler;
WiFiMulti wifiMulti;
//  WebServer server(80);
HardwareSerial mbSerial(1);
ledc_channel_config_t ledc_channel[2];  //
Preferences preferences;

//order here is important
#include "TimeStuff.h"
#include "Utility.h"            // utility functions
#include "WLAN.h"               // wireless stuff
//#include "edit.h"               // ACE editor
#include "MBus.h"               // Handle MODBUS and datatype conversion
#include "ControllerFiles.h"    // Read and parse controller .csv files
#include "HTML.h"               // Common HTML stuff
#include "RestPage.h"           // REST API
#include "PS.h"                 // status, charge and other pages for Prostar models
#include "WebPages.h"           // stuff to serve content

#include "WebCmd.h"
#include "Setups.h"
#include "OTA.h"
#include "Web.h"                // starts up web server


void setup() {
  pinMode(I2C_SDA_RESET, INPUT);
  pinMode(BOOT_SW, INPUT_PULLUP); // to read the boot switch
  #ifdef WROVER
    pinMode(USB_PWR_DET, INPUT);
    adcAttachPin(USB_CC1_PIN);
    adcAttachPin(USB_CC2_PIN);
    analogSetPinAttenuation(USB_CC1_PIN, ADC_6db);
    analogSetPinAttenuation(USB_CC2_PIN, ADC_6db);
  #endif
  attachSDCardIRQ();            // get an interrupt when card inserted/removed
    
  WiFi.macAddress(mac);
  my_MAC = "0" + String(mac[5],HEX); // this pads the octets
  my_MAC = "0" + String(mac[4],HEX) + my_MAC.substring(my_MAC.length()-2) ;
  my_MAC = "0" + String(mac[3],HEX) + my_MAC.substring(my_MAC.length()-4) ;
  my_MAC = my_MAC.substring(my_MAC.length()-6) ;
  my_name = HOSTNAME + String("-") + my_MAC;
  my_hostname = my_name;
  logFileName = "/"+ my_name + ".log";
  setupRtcSQW();  // real time clock 1/sec interrupt
  setupComms();   // serial port stuff
  setupFS();      // filesystems

  if ( ESP.getSketchSize() + 4096 < ESP.getFreeSketchSpace() ) {
    largeFlash = true;
  }

  if (psramInit()){
    psRAMavail=true;
    debugMsg(F("PS-RAM available"),1);
    #ifdef PS_RAM
      debugMsgln(F("(using)"),1);
    #endif
    #ifndef PS_RAM
      debugMsgln(F("(not using)"),1);
      psRAMavail=false;
    #endif    
  }

 
  preferences.begin("eeprom", false);   // this bit can go away in the future
  preferences.clear();                  // just here to clear old eeprom from nvs
  preferences.end();

  getPreferences();
  getWLANs();
  setupWLAN();
  setupClocks();
  setupModbus();
  modbusTCP.begin();
  debugMsgln("Getting modbus info for " + model,1);
  getFile(model);
  if (getSn()) {
    debugMsg(F("Controller serial number: "),1);
    debugMsgln(ctlSerialNum,1);
  } else {
    debugMsgln(F("Failed to get serial number."),1);
  }
  
  refreshCtlLogFile();

  server.begin();
  startWeb();
  getRtcTime();
  WiFi.setTxPower(WIFI_POWER_19dBm); // 15 is about 1/3 the power of the default 19.5 dBm

  setEvents(); // setup regular events.
  blinkySetup(WLAN_PIN,WLAN_PIN_OLD);
  blinky(1,ULONG_MAX,0,0); // LED OFF
  debugMsgln(F("Leaving setup()"),1);
} // setup()

void loop() {
  events(); // for EZTime  
  checkNtp();
  if (sd_card_changed) changeSDCard();
  #ifndef DEBUG_ON
    serialPassthrough();
  #endif
  asynchOTA.loop();
// This handles connections to TCP/502 for Modbus TCP from MSView
  if (!modbusClient.connected()) {
    modbusClient = modbusTCP.available();
  } else {
    mbusTCP();
  }

  long unsigned int boot_reset = millis() | 1; // can never be 0 (arithmatic or)
  while (!digitalRead(BOOT_SW)) {             // BOOT switch is pressed
    delay(100);
    if (millis() > boot_reset + 5000) {       // switch pressed for more than 5 seconds
      boolean wlanLedState = true;
      boot_reset = 0;                         // doing a reset
      wlanLedState = !wlanLedState;
      setWlanLED(wlanLedState);
      delay(50);                             // blink fast if switch pressed and doing reset
    }
  }                                           // keep looping as long as BOOT is pressed
  if (boot_reset == 0) {                      // reset to defaults requested
    debugMsgln(F("BOOT held, resetting to defaults."),1);    
    resetPreferences();
    reboot();
  }

/*
 *  Blink the LED based on current connection state.
 */
  if (led_change_done) blinky();                        // maintenance for LED, no need to call if still changing
  if (WiFi.softAPgetStationNum()) {                     // AP client connected, fast
    if ( blinkyState != lss_APCLIENT ) {
      blinkyState = lss_APCLIENT;
      blinky(300,1000);
    }
  } else if (WiFi.status() == WL_CONNECTED) {           // Connected as STA, flash every 2.5 sec
    if ( blinkyState != lss_STATION ) {
      blinkyState = lss_STATION;
      blinky(750, 2500, 255, 8);
    }
  } else {                                              // no connections, slower/dimmer
    if ( blinkyState != lss_IDLE ) {
      blinkyState = lss_IDLE;
      blinky(5000, 5000, 64, 4);
    }
  }
  myWDT = 60; // reset watchdog

} // loop()

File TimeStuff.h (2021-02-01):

#include <DS3231.h>   // Northern Widget LLC, et al 1.0.2, via IDE, public domain
#include <extEEPROM.h> // Jack Christensen, 3.4.1, via IDE licensed under CC BY-SA 4.0.
#include <EwmaT.h> // 1.0.2 via IDE, jonnieZG, https://github.com/jonnieZG/EWMA, MIT license
#include <ezTime.h> // 0.8.3 Rop Gonggrijp, via IDE

//#define RTCtestNtpSet 2  // deliberately sets RTC wrong for testing. 1=slow 997 ms, 2=fast 997 ms

// forward declarations
void debugMsg(String msg, int level=1);
void debugMsgln(String msg, int level=1);
void tryWLAN();
void ctlLog();
void stopLogDaily();
signed char getAgingTrim();
void oncePerFive();
void oncePerHour();
// end forward declarations

String getNtpTZ();
String getNtpServer();
unsigned short int getNtpPoll();

#define RTC_EEPROM_SIZE 4096
#define RTC_EEPROM_SIG "mjs!"

/*
 * EEPROM on DS3231 module
 * 0    (1) Last set aging trim (so we have it if battery goes away)
 * 1-2  (2) Year
 * 3    (1) Month
 * 4    (1) Day
 * 5    (1) Hour
 * 6    (1) Minute
 * 7    (1) Second
 * 8-11 (4) Last time set (Unix time)
 * 
 * 4092-4095 (4)  Valid signature (RTC_EEPROM_SIG)
 */
#define RtcEepromAge 0
#define RtcEepromYear 1
#define RtcEepromMonth 3
#define RtcEepromDay 4
#define RtcEepromHour 5
#define RtcEepromMinute 6
#define RtcEepromSecond 7
#define RtcEepromLastSetTime 8
#define RTC_DRIFT_FACTOR 1.0      // multiply drift trim correction by this

#define NTP_DEFAULT_TZ "EST+5EDT,M3.2.0,M11.1.0"   // full POSIX format
#define NTP_DEFAULT_INTERVAL 7207                 // seconds, best if not a multiple of 60
#define NTP_DEFAULT_SERVER "0.pool.ntp.org"
#define NTP_MIN_INTERVAL 601                      // seconds
#define NTP_MAX_INTERVAL 65535                    // ~18 hours

DS3231 Clock;
extEEPROM rtc_eeprom(kbits_32, 1, 32, 0x57);
#define RTC_I2C_ADDR 0x68
#define RTC_EEPROM_I2C_ADDR 0x57  // ZS-042/HW-84 modules have pullups on A0-A2
#define RTC_DEFAULT_TRIM 0        // aging trim for ds3231, higher is slower
                                  // ~0.1 ppm per (~9 ms/day, 0.26 sec/month), higher is slower, 
                                  // 11.6 ppm is ~ 1 sec/day
#define RTC_MAX_UNSYNC 125        // adjust when we're this many ms out of sync with NTP, for 601 sec NTP polls
#define SQW_PIN 14                // GPIO 14 (D5) on both, SQW from DS3231

bool rtcPresent = false;
bool rtcNeedsTime = false;
timeStatus_t ntp_state;           // timeNotSet, timeSet, timeNeedsSync
bool twentyFourHourClock = true;
bool Century=false;
bool h12;
bool PM;
int Year = 2019;
byte Month = 4, Day = 1, Weekday = 1, Hour = 0, Minute = 0, Second = 0;  // April fool's
volatile long int rtc_ms = 0;
// below underflows with negatives, so all uses add 1000000.
EwmaT <long int> rtc_diff_ewmat(2, 10, 1000000); // 2/10:weight for new additions, 1000000:starting value
long int rtc_diff_filtered = 0; // filtered value
int rtc_IRQ = false;  // faster to set an int than a bool?
unsigned long int rtc_secs;
String ntpServer = NTP_DEFAULT_SERVER;
unsigned short int ntpInterval = NTP_MAX_INTERVAL;
String ntpTZ = NTP_DEFAULT_TZ;  //posix string
String tzName;  // used for lookup
String tzPosix; // used for lookup
Timezone myTZ;
unsigned int rtc_max_unsync = RTC_MAX_UNSYNC * sqrt(ntpInterval/600);  // can get more out of sync with longer ntp updates


String ntp_state_string(timeStatus_t state) {
  if ( state == timeSet ) return F("NTP time set");
  if ( state == timeNotSet ) return F("NTP time not set");
  if ( state == timeNeedsSync ) return F("NTP time needs sync");
  return F("err"); 
}
void setupRtcSQW() {
  pinMode(SQW_PIN, INPUT);            // From DS3231 square wave output 1 Hz - 8.192 KHz
  digitalWrite(SQW_PIN, HIGH);        // internal pullup
}

// ************************************************************
// Read/write the eeprom on the RTC module
// ************************************************************
byte read_rtc_eeprom(int address) {
  // Read a byte at address in EEPROM memory.
  byte data[1];
  byte i2cStat = rtc_eeprom.read(address, data, 1);
  debugMsg(F("Reading RTC eeprom, "),5);
  debugMsgln(String(address)+": "+String(data[0]),5);
  return data[0];
}

void write_rtc_eeprom(int address, byte data) {
  debugMsg(F("Writing RTC eeprom, "),4);
  debugMsgln(String(address)+": "+String(data),4);
  byte writebyte[1];
  writebyte[0] = data;
  byte i2cStat = rtc_eeprom.write(address, writebyte, 1);
  // Write cycle time (tWR). See EEPROM memory datasheet for more details.
  delay(10);
}

void setRtcLastSetTime(time_t set_time) {
  if (!rtcPresent) return;
  debugMsgln(F("setRtcLastSetTime"),2);
  time_t unow = set_time;
  write_rtc_eeprom(RtcEepromYear, Year>>8);
  write_rtc_eeprom(RtcEepromYear+1, Year%256);
  write_rtc_eeprom(RtcEepromMonth, Month);
  write_rtc_eeprom(RtcEepromDay, Day);  
  write_rtc_eeprom(RtcEepromHour, Hour);
  write_rtc_eeprom(RtcEepromMinute, Minute);
  write_rtc_eeprom(RtcEepromSecond, Second);
  for (int i=0 ; i<4 ; i++) {
    write_rtc_eeprom(RtcEepromLastSetTime+i, unow%256);
    unow = unow >> 8;
  }
}
    
time_t getRtcLastSetTime() {
  if (!rtcPresent) return 0;
  time_t utime = 0;
  for (int i=3; i>-1; i--) {  // read high byte first so we can bit shift
    utime = utime << 8;
    utime += read_rtc_eeprom(RtcEepromLastSetTime+i);
  }
  return utime;
}

time_t getUnixTime() {
  time_t unow;
  if (rtcPresent){
    RTClib RTC;
    DateTime now = RTC.now();
    unow = now.unixtime();
  } else {
    unow = UTC.now();  // from ntp
  }
  return unow;
}

void writeRtcEepromSig() {
  String chkstr = F(RTC_EEPROM_SIG);
  for (int i = 0; i < 4 ; i++) {
    write_rtc_eeprom(i + RTC_EEPROM_SIZE -4, chkstr[i]);
  }
  debugMsgln("Wrote RTC eeprom sig: " + chkstr,3);
}

// ************************************************************
// Get the time from the RTC
// ************************************************************
void getRtcTime() {
  if (rtcPresent) {
    Year = Clock.getYear() + 2000;
    Month = Clock.getMonth(Century);
    Day = Clock.getDate();
    Weekday = Clock.getDoW();
    Hour = Clock.getHour(twentyFourHourClock, PM);
    Minute = Clock.getMinute();
    Second = Clock.getSecond();
    // Make sure the clock keeps running even on battery
    if (!Clock.oscillatorCheck())
      Clock.enableOscillator(true, true, 0);
  } 
}

String getRtcTimeString(int full = 1) {  // form: 1=full, 0=HMS
  if (rtcPresent) {
    String RTCTime = "";
    getRtcTime();
    if (full) {
      RTCTime = String(Month)+"/"+String(Day, DEC)+"/"+String(Year, DEC)+" ";
    }
    RTCTime += String(Hour, DEC)+": "+String(Minute, DEC)+": "+String(Second, DEC);
    return RTCTime;
  }
}

// ************************************************************
// Set the date/time in the RTC 
// ************************************************************
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

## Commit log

2019-11-24 more files
    [MBus-WeMOS.brd, MBus-WeMOS.sch]
2019-12-09 littlefs, editor
    [PS-MPPT.csv, PS-PWM.csv, SS-MPPT.csv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]
2019-12-18 ESP32 work
    [MStar-WLAN.brd, MStar-WLAN.sch]
2019-12-24 clean up, ntp fix
    [MStar-WLAN.ino, PS.h, Utility.h]
2019-12-31 time fixes, REST improvements
    [MStar-WLAN.ino, RestPage.h, TimeStuff.h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]
2020-01-03 more time fixes, prep for SD Card
    [largest_spiffs_16MB.csv]
2020-01-06 bug fixes. SD Card support. New PCB.
    [MStar-WLAN.brd, MStar-WLAN.sch]
2020-01-08 redo debug logging, bug fixes
    [MBus.h, MStar-WLAN.ino, PS.h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]
2020-05-26 ESP32. Logging. Dynamic status update. More.
    [MStar-WLAN.brd, MStar-WLAN.sch, PS-MPPT.csv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]
2020-10-06 clean up
    [PS-MPPT.csv, PS-PWM.csv, SS-MPPT.csv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]
2020-10-30 Logging, hardware change to USB C
    [MStar-WLAN.brd, MStar-WLAN.sch]
2020-10-31 Fix setTime buttons
2020-11-01 Add reset to default (press BOOT for 5+ s)
    [MStar-WLAN.ino]
2020-11-06 hardware, configurable hostname
    [MStar-WLAN.brd, MStar-WLAN.sch]
2020-11-08 Arduino IDE work
    [MStar-WLAN_16MB.csv, MStar-WLAN_4MB.csv, MStar-WLAN_8MB.csv]
2020-11-08 Arduino IDE
2020-11-11 Hardware update
    [MStar-WLAN.brd, MStar-WLAN.sch]
2020-11-13 fix sd card size
    [MBus.h, MStar-WLAN.ino, Utility.h]
2020-11-18 fancy LED
2020-11-21 LED done by hardware, logging spares
2021-01-14 Hardware, charting, much more
    Hardware updated for USB-C and to support Devkit-C.
    Charting using an RRD database and JavascriptRRD / FLOT.
    Show temperature in C or F on /status page.
    Configurable logging period for traditional log.
    Lots of bug fixes and tweaks, especially in Modbus.
    [MStar-WLAN.brd, MStar-WLAN.sch, PS-MPPT.csv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]
2021-01-20 fix solar power calc
    [MStar-WLAN.ino, PS.h, TimeStuff.h]
2021-02-01 maxP logging, minor fixes/tweaks
    [PS-PWM.csv]
